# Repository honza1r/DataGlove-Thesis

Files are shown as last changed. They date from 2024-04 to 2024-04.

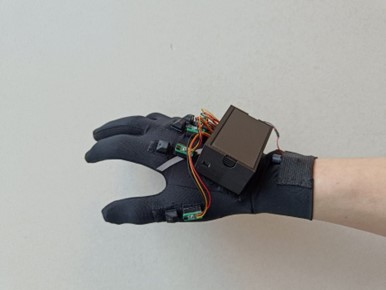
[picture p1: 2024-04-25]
Glove Pictures and Videos/Picture1.jpg

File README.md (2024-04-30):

# Open Source Dataglove - Master Thesis
This repository pools all of the technical files and instructions needed to replicate the dataglove that was developed as a master thesis. The repository is split into two main sections; hardware and software. 
## Hardware
The hardware section contains all production files as well as the microcontroller code. It also contains a matlab file with some matlab code and simulink model that was used very early in the development to test and create the Madgwick fusion algorithm. 
## Software
Software contains all intructions regarding connecting the glove to a ROS network running on a computer, as well as a unity application that serves as a demo for the glove. Connection to the demo is done over bluetooth serial.

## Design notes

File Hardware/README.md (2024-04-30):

# Hardware
All of the files given are the latest files and no previous versions are provided. That is mainly because the previous versions do not provide any value anymore.  
## PCB
It is important to note that the PCB contains a chip for regulating battery voltage to 5V,h however this chip seems to only work for about ~60 minutes and then causes a short circuit, killing itself and yhe battery. 
It is recommended to either use external power bank via the USB-C connector or you can redesign the PCB to have proper battery management.  
## ESP32 Code
The current code contains numerous functions that can be commented or uncommetned, depending on the desired data output. It is recommended to have a quick look over the main loop() function and its comments.
## CAD
The CAD files are given as STL and Siemens NX. A lot of the components are attached to the glove using velcro and velcro straps.
## MatLab
The simulink model used for developing and testing the Madgwick fusion algorithm is included. Also the Matlab script used for obtaining the magnetometer matrices is included.

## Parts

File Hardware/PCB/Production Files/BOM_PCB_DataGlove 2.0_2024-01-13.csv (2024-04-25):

ID | Name | Designator | Footprint | Quantity | Manufacturer Part | Manufacturer | Supplier | Supplier Part | Price
1 | SS54_C22452 | D2,D1 | SMA_L4.4-W2.8-LS5.4-R-RD | 2 | SS54 | MDD | LCSC | C22452 | 0.038
2 | SK12D07VG3_C431547 | SW1 | SW-TH_SK12D07VG3 | 1 | SK12D07VG3 | SHOU HAN | LCSC | C431547 | 0.017
3 | HDR-M-2.54_1x1 | J1,J2,J3,J4,J5 | HDR-M-2.54_1X1 | 5 |  |  | LCSC | C81276 | 0.007
4 | 100nF | ESPC17,ESPC18,ESPC20,ESPC21,ESPC22,ESPC23,ESPC7,ESPC3,ESPC5,ESPC8,ESPC9,ESPC11,ESPC12,ESPC16,C7 | C0402 | 15 | CL05B104KO5NNNC | SAMSUNG(三星) | LCSC | C1525 | 0.001
5 | 1uF | C1 | C0402 | 1 | CL05A105KA5NQNC | SAMSUNG(三星) | LCSC | C52923 | 0.004
6 | 100uF | C11 | C1206 | 1 | CL31A107MQHNNNE | SAMSUNG(三星) | LCSC | C15008 | 0.063
7 | 2.2uF | C12 | C0402 | 1 | CL05A225MQ5NSNC | SAMSUNG(三星) | LCSC | C12530 | 0.003
8 | XH-2AW_C2908611 | CN1 | CONN-TH_XH-2AW_C2908611 | 1 | XH-2AW | HCTL(华灿天禄) | LCSC | C2908611 | 0.011
9 | 10uF | ESPC19,ESPC1,ESPC2,ESPC10,ESPC13,ESPC14,ESPC15 | C0402 | 7 | CL05A106MQ5NUNC | SAMSUNG(三星) | LCSC | C15525 | 0.005
10 | 51kΩ | R18 | R0402 | 1 | 0402WGF5102TCE | UNI-ROYAL(厚声) | LCSC | C25794 | 0.001
11 | 750kΩ | R19 | R0603 | 1 | 0603WAF7503T5E | UNI-ROYAL(厚声) | LCSC | C23240 | 0.001
12 | 1MΩ | R21 | R0402 | 1 | 0402WGF1004TCE | UNI-ROYAL(厚声) | LCSC | C26083 | 0.001
13 | 200kΩ | R22 | R0402 | 1 | 0402WGF2003TCE | UNI-ROYAL(厚声) | LCSC | C25764 | 0.001
14 | DRV2605LDGSR | U5 | VSSOP-10_L3.0-W3.0-P0.50-LS4.9-BL | 1 | DRV2605LDGSR | TI(德州仪器) | LCSC | C527464 | 1.726
15 | 1-1825027-7 | U6,U7 | SW-TH_KH-6X6X4.3H-ZJ | 2 | 1-1825027-7 | TE Connectivity(美国泰科) | LCSC | C592923 | 0.169
16 | SM03B-SRSS-TB(LF)(SN)(P) | U10,U11,U12,U13,U14 | CONN-SMD_SM03B-SRSS-TB-LF-SN-P | 5 | SM03B-SRSS-TB(LF)(SN) | JST | LCSC | C160403 | 0.137
17 | AMS1117-3.3 | U4 | SOT-223-3_L6.5-W3.4-P2.30-LS7.0-BR | 1 | AMS1117-3.3 | AMS | LCSC | C6186 | 0.141
18 | LSM6DSO32TR | U3 | LGA-14_L3.0-W2.5-P0.50-TL | 1 | LSM6DSO32TR | ST(意法半导体) | LCSC | C1864162 | 7.011
19 | YTC1P-6030-01 | U1,U2 | CONN-SMD_YTC1P-3015-01 | 2 | YTC1P-6030-01 | YIYUAN(怡远) | LCSC | C5221285 | 0.111
20 | 4.7uF | ESPC6 | C0402 | 1 | CL05A475MP5NRNC | SAMSUNG(三星) | LCSC | C23733 | 0.006
21 | 22uF | ESPC4 | C0603 | 1 | CL10A226MQ8NRNC | SAMSUNG(三星) | LCSC | C59461 | 0.008
22 | 0805G (Green) | ESPLED2 | LED0805-R-RD | 1 | KT-0805翠绿 | KENTO | LCSC | C2297 | 0.014
23 | SS8050_C2150 | ESPQ1,ESPQ2 | SOT-23-3_L2.9-W1.3-P1.90-LS2.4-BR | 2 | SS8050 | CJ(江苏长电/长晶) | LCSC | C2150 | 0.015
24 | 5.1kΩ | ESPR1,ESPR2,ESPR3 | R0402 | 3 | 0402WGF5101TCE | UNI-ROYAL(厚声) | LCSC | C25905 | 0.001
25 | 22Ω | ESPR5 | R0402 | 1 | 0402WGF220JTCE | UNI-ROYAL(厚声) | LCSC | C25092 | 0.001
26 | 0Ω | ESPR6,ESPR7 | R0402 | 2 | 0402WGF0000TCE | UNI-ROYAL(厚声) | LCSC | C17168 | 0.001
27 | 10kΩ | ESPR8,ESPR9,ESPR16,ESPR17,ESPR18,ESPR19,ESPR20,R15,R13 | R0402 | 9 | 0402WGF1002TCE | UNI-ROYAL(厚声) | LCSC | C25744 | 0.001
28 | 22kΩ | ESPR10 | R0402 | 1 | 0402WGF2202TCE | UNI-ROYAL(厚声) | LCSC | C25768 | 0.001
29 | 47kΩ | ESPR11 | R0402 | 1 | 0402WGF4702TCE | UNI-ROYAL(厚声) | LCSC | C25792 | 0.001
30 | 1kΩ | ESPR12,R8,R14 | R0402 | 3 | 0402WGF1001TCE | UNI-ROYAL(厚声) | LCSC | C11702 | 0.001
31 | 470kΩ | R2 | R0402 | 1 | 0402WGF4703TCE | UNI-ROYAL(厚声) | LCSC | C25790 | 0.001
32 | SMF6.0CA_C2990473 | ESPU1,ESPU3,ESPU4 | SOD-123FL_L2.8-W1.8-LS3.7-BI | 3 | SMF6.0CA | Liown(里阳半导体) | LCSC | C2990473 | 0.029
33 | 6.8uH | L1 | IND-SMD_L4.5-W4.5_SMMS0420 | 1 | SMMS0420-6R8M | SXN(顺翔诺) | LCSC | C133194 | 0.194
34 | KT-0603R | LED1 | LED0603-RD | 1 | KT-0603R | KENTO | LCSC | C2286 | 0.006
35 | MMUN2133LT1G | Q1 | SOT-23-3_L2.9-W1.6-P1.90-LS2.8-BR | 1 | MMUN2133LT1G | onsemi(安森美) | LCSC | C86182 | 0.024
36 | 2MΩ | R4 | R0603 | 1 | 0603WAF2004T5E | UNI-ROYAL(厚声) | LCSC | C22976 | 0.001
37 | 680kΩ | R5 | R0603 | 1 | 0603WAF6803T5E | UNI-ROYAL(厚声) | LCSC | C25822 | 0.001
38 | 2N7002 | Q3,Q4 | SOT-23-3_L2.9-W1.3-P1.90-LS2.4-BR | 2 | 2N7002 | CJ(江苏长电/长晶) | LCSC | C8545 | 0.015
39 | HDR-F-2.54_1x2 | H8 | HDR-F-2.54_1X2 | 1 |  |  | LCSC | C49661 | 0.035
40 | AT24C256C-SSHL-T | AT24C256C | SOIC-8_L4.9-W3.9-P1.27-LS6.0-BL | 1 | AT24C256C-SSHL-T | MICROCHIP(美国微芯) | LCSC | C6482 | 0.396
41 | CP2102-GMR | CP2102 | WQFN-28_L5.0-W5.0-P0.50-BL-EP3.2 | 1 | CP2102-GMR | SILICON LABS(芯科) | LCSC | C6568 | 2.021
42 | ESP32-WROOM-32E(8MB) | ESP32 | WIFI-SMD_ESP32-WROOM-32E | 1 | ESP32-WROOM-32E-N8 | ESPRESSIF(乐鑫) | LCSC | C701342 | 3.661
43 | MMC5603NJ | MMC5603 | FLIPCHIP-4_L0.8-W0.8-R2-C2-P0.40-TL | 1 | MMC5603NJ | MEMSIC(美新) | Mouser | C404328 | 0.352
44 | TPS61090RSAR | TPS61090 | QFN-16_L4.0-W4.0-P0.65-BL-EP2.2 | 1 | TPS61090RSAR | TI(德州仪器) | LCSC | C206167 | 3.034
45 | TYPEC-304-ACP16 | USB-C | USB-C-SMD_TYPE-C-16P-1 | 1 | TYPEC-304-ACP16 | XUNPU(讯普) | LCSC | C2982555 | 0.127

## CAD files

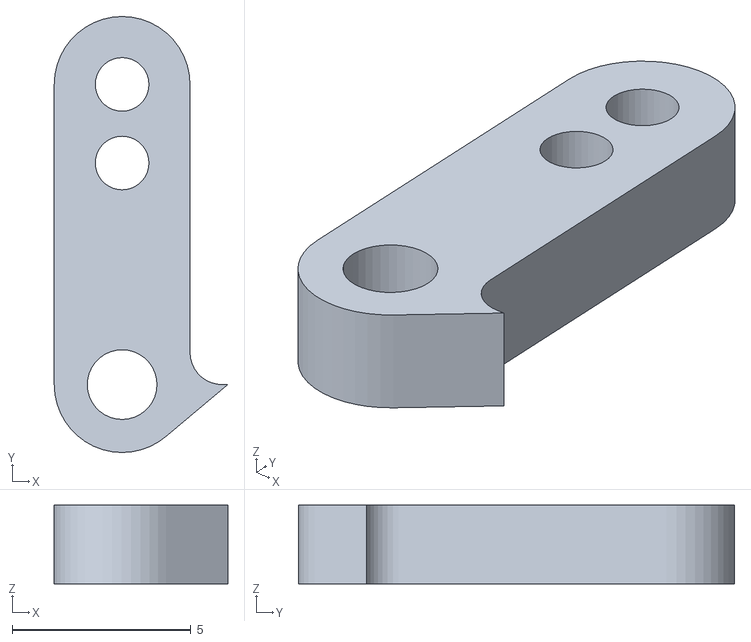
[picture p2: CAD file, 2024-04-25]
Hardware/CAD/Lever V3.stl
4.86 x 12.2 x 2.20

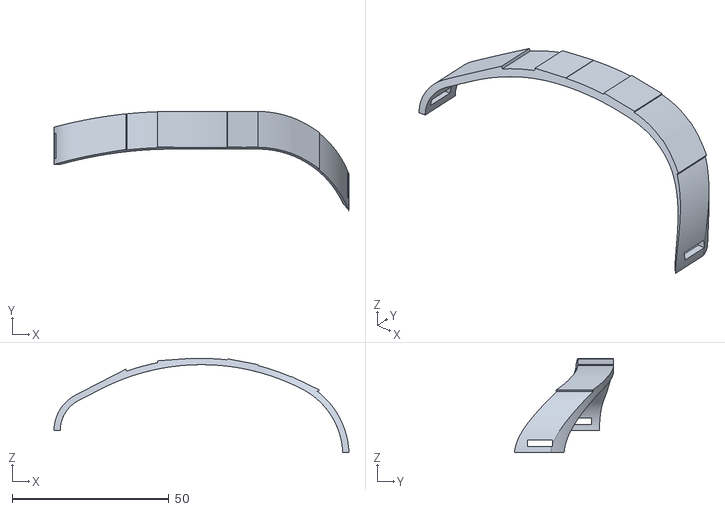
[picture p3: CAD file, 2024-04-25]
Hardware/CAD/Hand Strap V6.stl
94.0 x 31.6 x 30.0

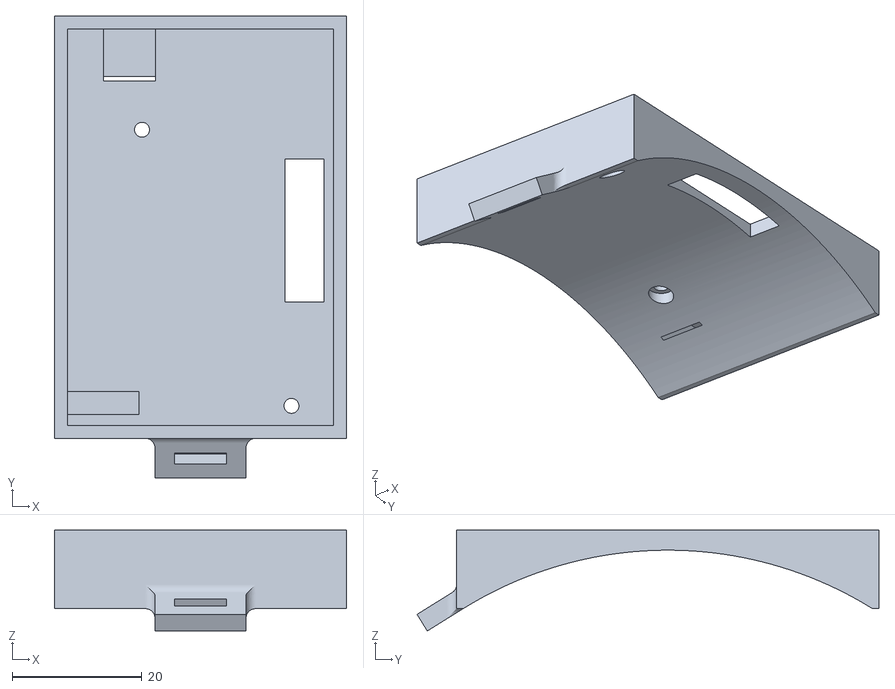
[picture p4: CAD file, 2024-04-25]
Hardware/CAD/Lower Part V2.stl
45.0 x 71.1 x 15.5

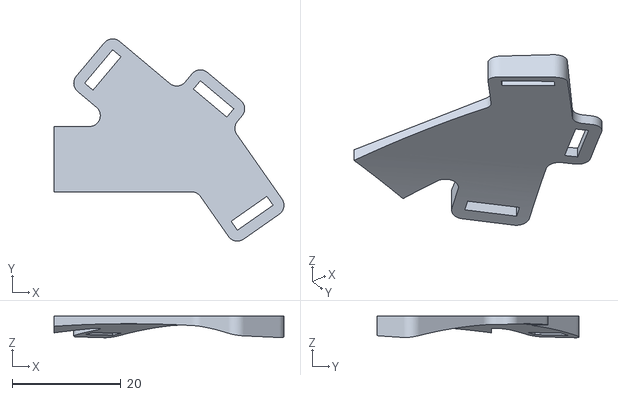
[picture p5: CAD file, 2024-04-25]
Hardware/CAD/Thumb Strap V2.stl
42.2 x 37.1 x 3.96

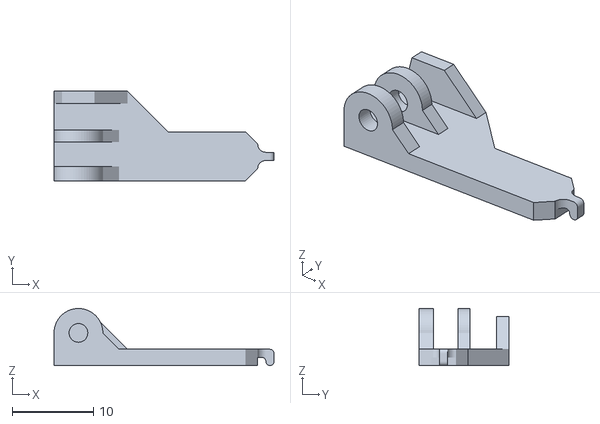
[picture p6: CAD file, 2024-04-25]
Hardware/CAD/Base V3.stl
27.0 x 11.0 x 7.00

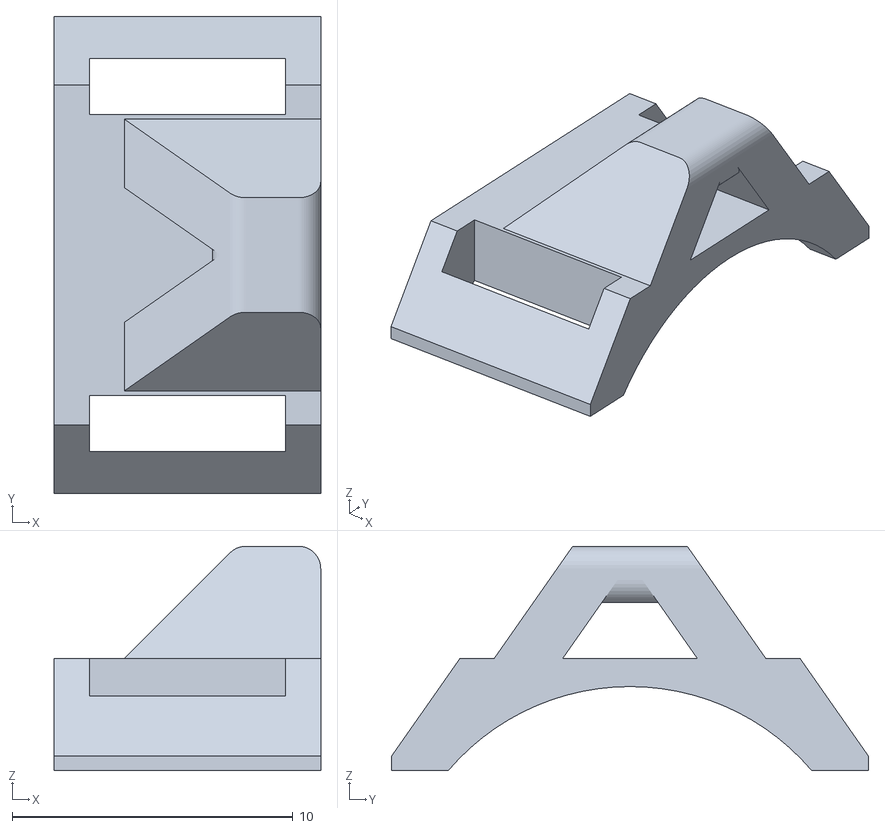
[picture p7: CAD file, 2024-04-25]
Hardware/CAD/String Holder V2.stl
9.50 x 17.0 x 8.00

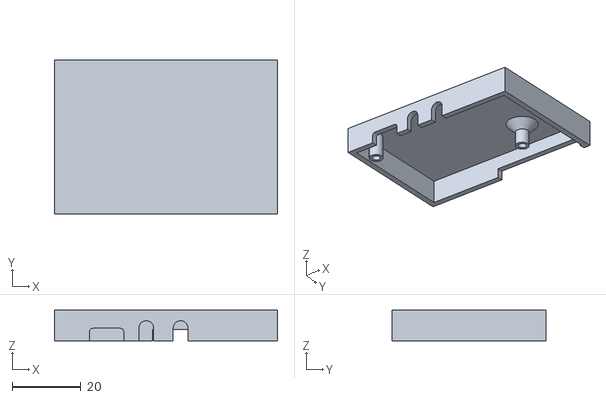
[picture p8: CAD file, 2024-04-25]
Hardware/CAD/Upper Part V2.stl
65.0 x 45.0 x 9.00

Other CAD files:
Hardware/CAD/Base V3.prt
Hardware/CAD/Hand Strap V6.prt
Hardware/CAD/Lever V3.prt
Hardware/CAD/Lower Part V2.prt
Hardware/CAD/String Holder V2.prt
Hardware/CAD/Thumb Strap V2.prt
Hardware/CAD/Upper Part V2.prt

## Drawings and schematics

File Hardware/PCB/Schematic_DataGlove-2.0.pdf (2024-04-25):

## USB-C Connection

## Power

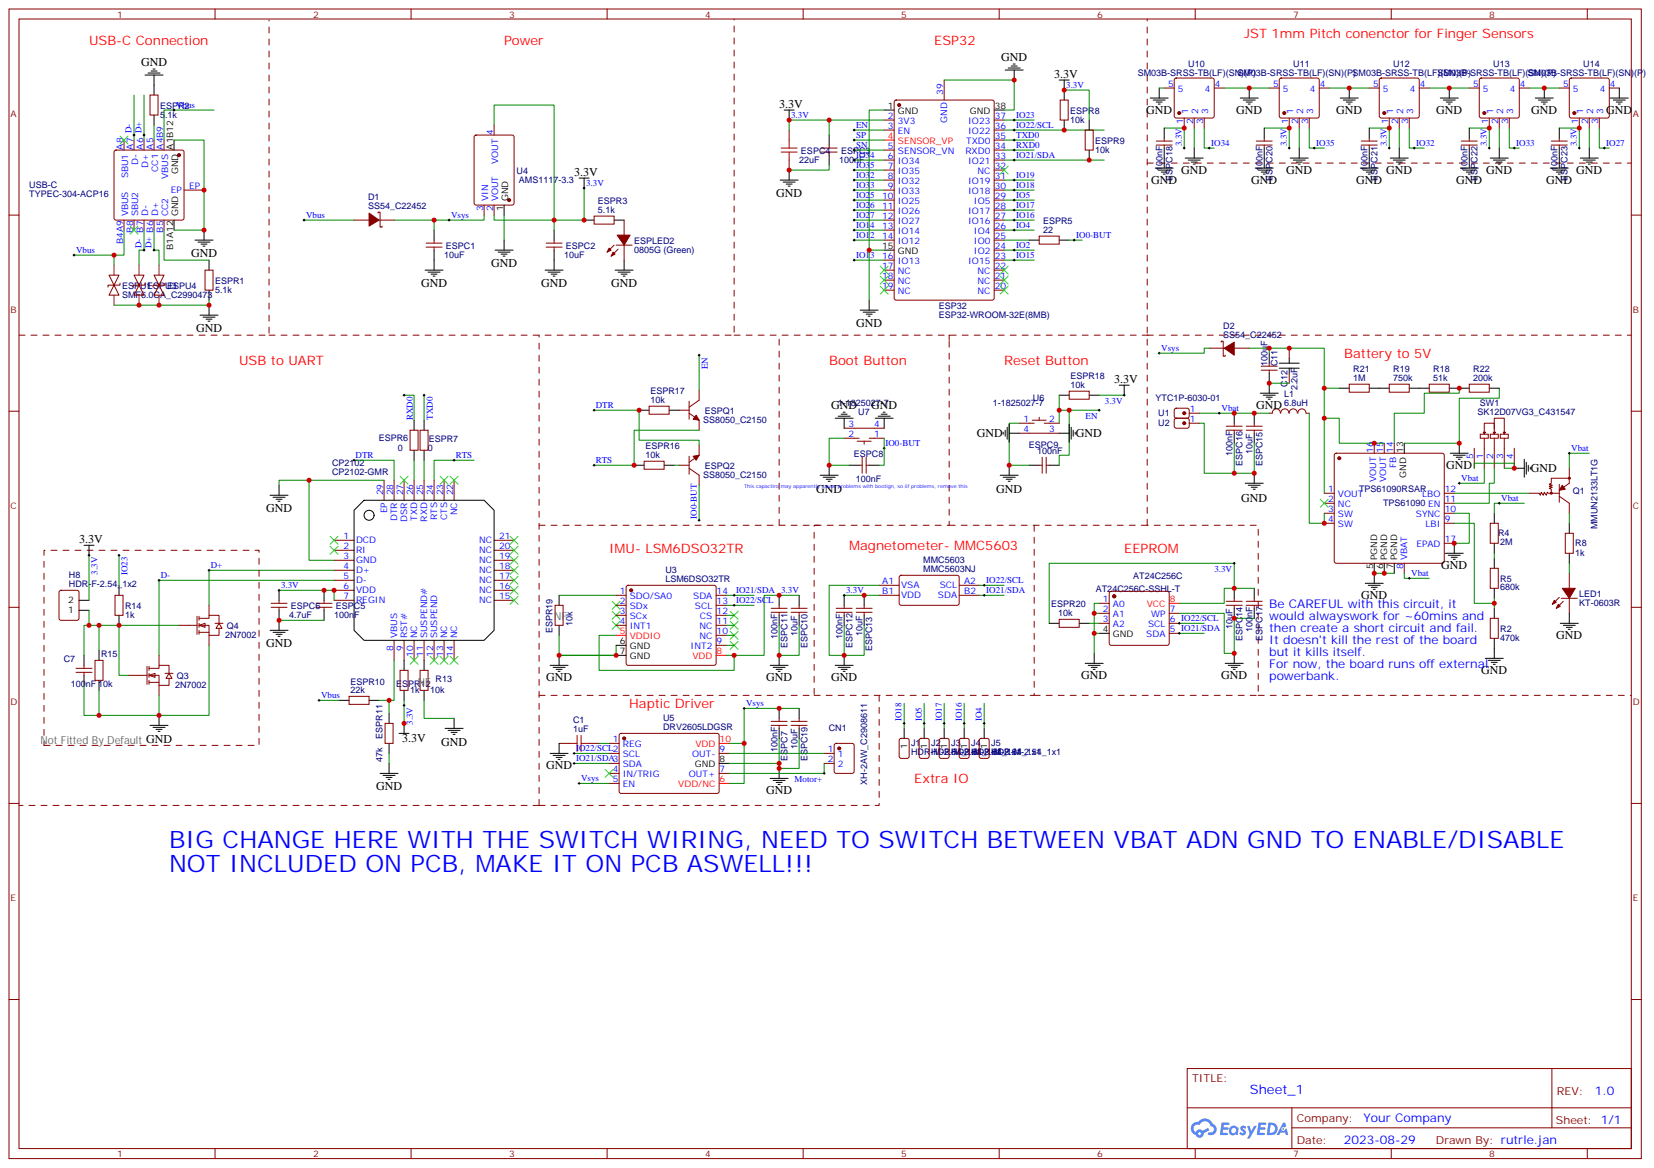
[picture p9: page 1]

JST 1mm Pitch conenctor for Finger Sensors

SM03B-SRSS-TB(LF)(SN)(P)

GND A1B12 VBUS A4B9 CC1 A5 D+ A6 D- A7 SBU1 A8 VBUS B4A9 SBU2 B8 D- B7 D+ B6 CC2 B5 GND B1A12

NC 22 CTS 23 RTS 24 RXD 25 TXD 26 DSR 27 DTR 28 EP 29 47k ESPR11

This capactiro may apparently cause problems with bootign, so iif problems, remove this

Be CAREFUL with this circuit, it
would alwayswork for ~60mins and
then create a short circuit and fail.
It doesn't kill the rest of the board
but it kills itself.
For now, the board runs off external
powerbank.

Not Fitted By Default

BIG CHANGE HERE WITH THE SWITCH WIRING, NEED TO SWITCH BETWEEN VBAT ADN GND TO ENABLE/DISABLE
NOT INCLUDED ON PCB, MAKE IT ON PCB ASWELL!!!

Drawn By: rutrle.jan

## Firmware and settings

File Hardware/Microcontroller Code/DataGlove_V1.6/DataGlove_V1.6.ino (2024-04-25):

#include <Wire.h>
#include <BasicLinearAlgebra.h>
#include "BluetoothSerial.h"
#include "Adafruit_DRV2605.h"

Adafruit_DRV2605 drv;//define the on-board hpatic feedback motor drive ic

const char *pin = "1234"; // Change this to more secure PIN.
String device_name = "ESP32-DataGlove";

#if !defined(CONFIG_BT_ENABLED) || !defined(CONFIG_BLUEDROID_ENABLED)
#error Bluetooth is not enabled! Please run `make menuconfig` to and enable it
#endif

#if !defined(CONFIG_BT_SPP_ENABLED)
#error Serial Bluetooth not available or not enabled. It is only available for the ESP32 chip.
#endif

BluetoothSerial SerialBT;

using namespace BLA;

int IMUAdress = 0x6A;
int magnetometerAdress = 0x30;
int EEPROMAdress = 0x54;

//finger pings
#define thumb 34
#define index 35
#define middle 32
#define ring 33
#define pinky 27

//finger variables
int thumb_angle = 0;
int index_angle = 0;
int middle_angle = 0;
int ring_angle = 0;
int pinky_angle = 0;

//vibration variables
bool effectActivated = false;

//sensor variables
float magnetometer_cal [3]= {0.0,0.0,0.0};
float accel_cal [3] = {0.0,0.0,0.0};//I call it cal but techniccally it is the raw data, as we do not calibrate it, however it will be easier to understand the madgwick filter if all variables used there are called cal (preventing confusion)
float g [3] = {0.0,0.0,0.0};

//magnetometer corection matrices variables, to be read from EEPROM
typedef union{
  float number;
  uint8_t bytes[4];
} FLOATUNION_t; //this should allow me to access the individual float both as a float and as four bytes (the bytes I can the write and read from EEPROM one by one)
//for now, magnetometer correction matrices are defined here, they can be saved to the EEPROM if desired
float A_noMagnet[3][3] = {{0.972278205290896,0.025006895510657,-0.002802863108999},{0.025006895510657,0.982439238433754,0.021710960624373},{-0.002802863108999,0.021710960624373,1.048073705414568}};
float b_noMagnet[3] = {11.793363227227841,-45.088424713421226,-3.201333342740616};

// float A_to_save[9] = {1.0,0.0,0.0,0.0,1.0,0.0,0.0,0.0,1.0};//change these arrays with the values that you want saved
// float b_to_save[3] = {-96.207731134594850,-21.082673512359378,-42.121805843179710};

//output varaibles
float roll = 0.0;
float pitch = 0.0;
float yaw = 0.0;
float qx = 0.0;
float qy = 0.0;
float qz = 0.0;
float qw = 0.0;

//EKF Variables
float q[4] = {1.0,0.0,0.0,0.0}; //initial orientation, doesnt matter cause the filter converts to actaul orientation right away
float P[4][4] = {{0.1,0.0,0.0,0.0},
                 {0.0,0.1,0.0,0.0},
                 {0.0,0.0,0.1,0.0},
                 {0.0,0.0,0.0,0.1}};//currently defined as a full matrix, but once we do efficiecny optimalization, we'll probably find that we dont need to define the full matrix
float R_mag = 2.0;//the actaul estiamtions of R for accelerometer and magnetometer, shouldnt need to be tuned
float R_acc = 0.001;
float Q_val = 0.05;
//all of the following values are tunable and determine how well the filter will perform
float R_mag_max = 10.0;//2
float R_acc_max = 0.5;//1.0
float Q_max = 5.0;//0.1
float R_mag_min = 0.001;//1.0
float R_acc_min = 0.001;
float Q_min = 0.01;//0.01
float R_mag_slope = 10;//1
float R_acc_slope = 0.0005;//0.005
float Q_slope = 7.5;//0.1

//Madgwick Variables
float q0 = 1.0;
float q1 = 0.0;
float q2 = 0.0;
float q3 = 0.0;
float qDot1 = 0.0;
float qDot2 = 0.0;
float qDot3 = 0.0;
float qDot4 = 0.0;

float sampleFrequency = 200.0; //update frequency in Hz
int dataCounterLimit = int(sampleFrequency/25);//ensure we always send data to unity at 25hz
int dataCounter = 0;
int delayTime = int(1000/sampleFrequency);//1000 to make sure it is in MILLISECONDS!!!

bool inPairingMode = false;
unsigned long lastPairingCheckTime = 0;
const unsigned long pairingCheckInterval = 10000; // Check every 10 seconds

uint16_t dataOn = 25;
uint16_t dataOn_counter = 0;
uint16_t dataOff = 25;
uint16_t dataOff_counter = 0;


void setup() {
  Serial.begin(115200);
  SerialBT.begin(device_name);
  Serial.printf("The device with name \"%s\" is started.\nNow you can pair it with Bluetooth!\n", device_name.c_str());
  Wire.begin();
  magnetometerSetup();
  IMUSetup();
  // drv.begin();
  // drv.selectLibrary(1);
  // drv.setMode(DRV2605_MODE_INTTRIG); 
  // saveMagnetometerMatrices(A_to_save, b_to_save);//matrix A is ROW MAJOR, essentially spread into a noodle
  // delay(1000);
  // readMagnetometerMatrices();
  delay(1000);
}

void loop() {
  //magToCSV();//only uncomment in need of calibration of the magnetometer,sends magnetometer data in csv format, that can the be imported to Matlab
  readFingers();
  collectMagnetometerData();
  collectIMUData();
  //uncomment whichever filter you want to use
  EKF();
  //MadgwickFilter();
  //vibrations();//control the vibration feedback motor
  dataCounter++;
  if (dataCounter >= dataCounterLimit){
    printAnglesBT();//sends values over BT
    //sendCSVBT();//sends values over BT in CSV format
    //printAngles();//sends values over serial
    //Following block of code was used for smapling gestures, it send data for 1s and stops sending for 1s
//     if(dataOn_counter < dataOn){
//      sendCSVBT();
//      dataOn_counter++;
//     } 
//     else if(dataOff_counter < dataOff){
//       dataOff_counter++;
//     }
//     else{
//       dataOn_counter = 0;
//       dataOff_counter = 0;
//     }
    dataCounter = 0;
  }
  delay(delayTime);
}

void magnetometerSetup(){
  writeRegister(magnetometerAdress, 0x1C, 2);//configure Internal Control 1
  writeRegister(magnetometerAdress, 0x1A, 208);//configure ODR
  writeRegister(magnetometerAdress, 0x1B, 160);//configure Internal Control 0
  writeRegister(magnetometerAdress, 0x1D, 16);//configure Internal Control 2
}

void IMUSetup(){//watch out when using the slightly different chips (ranges and according mechanical characteristics!!!), relates to then transalting the output to proper units
  //this code has settigns for LSM6DSO
  writeRegister(IMUAdress, 0x10, 82);//configure CTRL1_XL, +-2g range, low-pass filter enable
  writeRegister(IMUAdress, 0x11, 84);//configure CTRL2_G, +-500DPS
  writeRegister(IMUAdress, 0x12, 4);//configure CTRL3_C
  writeRegister(IMUAdress, 0x13, 2);//configure CTRL4_C
  writeRegister(IMUAdress, 0x15, 7);//configure CTRL6_C, gyro filter bandwidth 12.2Hz (lowest) = 7
  writeRegister(IMUAdress, 0x17, 160);//configure CTRL8_XL, accell low-pas filter at 10Hz (ish), very low, 10.4Hz = 64, 2.08hz = 128, 1.04Hz = 160
  writeRegister(IMUAdress, 0x18, 226);//configure CTRL9_XL
}

void vibrations(){
  if (thumb_closed && index_closed && middle_closed && ring_closed && pinky_closed){
    if(!effectActivated){
      drv.setWaveform(0, 1);
      drv.setWaveform(1,0);
      drv.go();
      effectActivated = true;
    }
  }
  else{
    effectActivated = false;
  }
}

void collectMagnetometerData(){
  float magnetometer_raw [3] = {0.0,0.0,0.0};
  uint8_t buffer [9] = {0,0,0,0,0,0,0,0,0};
  int32_t x = 0;
  int32_t y = 0;
  int32_t z = 0;

  Wire.beginTransmission(magnetometerAdress);//start communication with magnetometer
  Wire.write(0x00);//access first output register (Xout0)
  Wire.endTransmission();//end communication with slave
  Wire.requestFrom(magnetometerAdress,9);//request all output bytes (until and including OUTZ_H_A)
  while(Wire.available() < 9);//wait until all bytes are received
  for (int i = 0; i < 9; i++){//feed all data into the buffer array
    buffer[i] = Wire.read();
  }

  x = (uint32_t)buffer[0] << 12 | (uint32_t)buffer[1] << 4 | (uint32_t)buffer[6] >> 4;//piece together all the bytes corresponding to 1 axis
  y = (uint32_t)buffer[2] << 12 | (uint32_t)buffer[3] << 4 | (uint32_t)buffer[7] >> 4;
  z = (uint32_t)buffer[4] << 12 | (uint32_t)buffer[5] << 4 | (uint32_t)buffer[8] >> 4;

  x -= (uint32_t)1 << 19;//fix center offsets(something to do with the fact data is sent unsigned but we need to make it singed, I think)
  y -= (uint32_t)1 << 19;
  z -= (uint32_t)1 << 19;

  magnetometer_raw[0] = float(x)*0.00625;//convert from count directly to uT (based on datasheet)
  magnetometer_raw[1] = float(y)*0.00625;
  magnetometer_raw[2] = float(z)*0.00625;
  //correct for soft and hard irons

  float magnetometer_corr [3] = {magnetometer_raw[0]-b_noMagnet[0], magnetometer_raw[1]-b_noMagnet[1], magnetometer_raw[2]-b_noMagnet[2]};
    magnetometer_cal[0] = {magnetometer_corr[0]*A_noMagnet[0][0]+magnetometer_corr[1]*A_noMagnet[1][0]+magnetometer_corr[2]*A_noMagnet[2][0]};
    magnetometer_cal[1] = {magnetometer_corr[0]*A_noMagnet[0][1]+magnetometer_corr[1]*A_noMagnet[1][1]+magnetometer_corr[2]*A_noMagnet[2][1]};
    magnetometer_cal[2] = {magnetometer_corr[0]*A_noMagnet[0][2]+magnetometer_corr[1]*A_noMagnet[1][2]+magnetometer_corr[2]*A_noMagnet[2][2]};
}

void collectIMUData(){
  float gyro_raw [3] = {0.0,0.0,0.0};
  float gyro_corr [3] = {0.01,-0.01,0.01};//this is a bias which is measured as the average vlaue of 100+ samples with the sensor at rest

  float accel_raw [3] = {0.0,0.0,0.0};
  
  Wire.beginTransmission(IMUAdress);//start communication with IMU
  Wire.write(0x22);//access first output register (OUTX_L_G)
  Wire.endTransmission();//end communication with slave
  Wire.requestFrom(IMUAdress,12);//request all output bytes (until and including OUTZ_H_A)
  while(Wire.available() < 12);//wait until all bytes are received

  //the output data is in some weird unit, so we multiply by 35 as based on table 3(mechanical characteristics) and the chosen range, and then by 3.14/(180.0*1000.0) to get it from mdps to rad/s
  //35.0*3.14/(180.0*1000.0)=0.000610865
  gyro_raw[0] = float(int16_t(Wire.read()|(Wire.read()<<8)));//read first byte (low byte of GYRO_X) and combine it with the second byte (high byte of GYRO_X) that has been shifted to the left), so on for the other variables
  gyro_raw[1] = float(int16_t(Wire.read()|(Wire.read()<<8)));//gotta make sure the two bytes read are interpreted correctly as a signed 16 bit integer and then we convert to float
  gyro_raw[2] = float(int16_t(Wire.read()|(Wire.read()<<8)));

  //the output data is in some weird unit, so we multiply by 0.244 as based on table 3(mechanical characteristics) and the chosen range, and then by 9.81/1000 to trasnfer from mg to m/s^2
  //0.244*9.81/1000.0=0.00239364, I cahnged range so it goes from 0.244 to 0.061
  accel_cal[0] = float(int16_t(Wire.read()|(Wire.read()<<8)))*0.00059841;
  accel_cal[1] = float(int16_t(Wire.read()|(Wire.read()<<8)))*0.00059841;
  accel_cal[2] = float(int16_t(Wire.read()|(Wire.read()<<8)))*0.00059841;  

  //the output data is in some weird unit, so we multiply by 35 as based on table 3(mechanical characteristics) and the chosen range, and then by 3.14/(180.0*1000.0) to get it from mdps to rad/s
  //35.0*3.14/(180.0*1000.0)=0.000610865, went form 1000DPS to 500DPS (so constant = 0.0003054325)
  g[0] = gyro_raw[0]*0.0003054325-gyro_corr[0];
  g[1] = gyro_raw[1]*0.0003054325-gyro_corr[1];
  g[2] = gyro_raw[2]*0.0003054325-gyro_corr[2];
}

void MadgwickFilter(){
  float beta = 2.0; //this is the main value we want to tune for the filter, it acts the same way as Kp in a PID controller,1, actaullly it is the elarning rate in gradient descent
  float qDot1 = 0.5*(-q1*(g[0]) - q2*(g[1]) - q3*(g[2]));
  float qDot2 = 0.5*(q0*(g[0]) + q2*(g[2]) - q3*(g[1]));
  float qDot3 = 0.5*(q0*(g[1]) - q1*(g[2]) + q3*(g[0]));
  float qDot4 = 0.5*(q0*(g[2]) + q1*(g[1]) - q2*(g[0]));

  float recipNorm = 0.0;

  if (!((accel_cal[0] == 0.0) && (accel_cal[1] == 0.0) && (accel_cal[2] == 0.0))){//ensures we only compute update if accelerometer readings are valid
    //normalize accelerometer readings
    recipNorm = 1/(sqrt(accel_cal[0]*accel_cal[0]+accel_cal[1]*accel_cal[1]+accel_cal[2]*accel_cal[2]));
    float ax = accel_cal[0]*recipNorm;
    float ay = accel_cal[1]*recipNorm;
    float az = accel_cal[2]*recipNorm;
    //normalize magnetometer readings
    recipNorm = 1/(sqrt(magnetometer_cal[0]*magnetometer_cal[0]+magnetometer_cal[1]*magnetometer_cal[1]+magnetometer_cal[2]*magnetometer_cal[2]));
    float mx = magnetometer_cal[0]*recipNorm;
    float my = magnetometer_cal[1]*recipNorm;
    float mz = magnetometer_cal[2]*recipNorm;
    //the following varaibles are "pre-calculated" once so we save some computatonal time by not doing the calcualtions over and over again when they are needed
    float twoq0mx = 2.0*q0*mx;
    float twoq0my = 2.0*q0*my;
    float twoq0mz = 2.0*q0*mz;

    float twoq1mx = 2.0*q1*mx;

    float twoq0 = 2.0*q0;
    float twoq1 = 2.0*q1;
    float twoq2 = 2.0*q2;
    float twoq3 = 2.0*q3;

    float twoq0q2 = 2.0*q0*q2;
    float twoq2q3 = 2.0*q2*q3;

    float q0q0 = q0*q0;
    float q0q1 = q0*q1;
    float q0q2 = q0*q2;
    float q0q3 = q0*q3;
    float q1q1 = q1*q1;
    float q1q2 = q1*q2;
    float q1q3 = q1*q3;
    float q2q2 = q2*q2;
    float q2q3 = q2*q3;
    float q3q3 = q3*q3;
    //reference direction of Earth's magnetic field
    float hx = mx*q0q0 - twoq0my*q3 + twoq0mz*q2 + mx*q1q1 + twoq1*my*q2 + twoq1*mz*q3 - mx*q2q2 - mx*q3q3;
    float hy = twoq0mx*q3 + my*q0q0 - twoq0mz*q1 + twoq1mx*q2 - my*q1q1 + my*q2q2 + twoq2*mz*q3 - my*q3q3;

    float twobx = sqrt(hx*hx + hy*hy);
    float twobz = -twoq0mx*q2 + twoq0my*q1 + mz*q0q0 + twoq1mx*q3 - mz*q1q1 + twoq2*my*q3 - mz*q2q2 + mz*q3q3;
    float fourbx = 2.0*twobx;
    float fourbz = 2.0*twobz;

    float s0 = -twoq2 * (2.0 * q1q3 - twoq0q2 - ax) + twoq1 * (2.0 * q0q1 + twoq2q3 - ay) - twobz * q2 * (twobx * (0.5 - q2q2 - q3q3) + twobz * (q1q3 - q0q2) - mx) + (-twobx * q3 + twobz * q1) * (twobx * (q1q2 - q0q3) + twobz * (q0q1 + q2q3) - my) + twobx * q2 * (twobx * (q0q2 + q1q3) + twobz * (0.5 - q1q1 - q2q2) - mz);
    float s1 = s1 = twoq3 * (2.0 * q1q3 - twoq0q2 - ax) + twoq0 * (2.0 * q0q1 + twoq2q3 - ay) - 4.0 * q1 * (1 - 2.0 * q1q1 - 2.0 * q2q2 - az) + twobz * q3 * (twobx * (0.5 - q2q2 - q3q3) + twobz * (q1q3 - q0q2) - mx) + (twobx * q2 + twobz * q0) * (twobx * (q1q2 - q0q3) + twobz * (q0q1 + q2q3) - my) + (twobx * q3 - fourbz * q1) * (twobx * (q0q2 + q1q3) + twobz * (0.5 - q1q1 - q2q2) - mz);
    float s2 = -twoq0 * (2.0 * q1q3 - twoq0q2 - ax) + twoq3 * (2.0 * q0q1 + twoq2q3 - ay) - 4.0 * q2 * (1 - 2.0 * q1q1 - 2.0 * q2q2 - az) + (-fourbx * q2 - twobz * q0) * (twobx * (0.5 - q2q2 - q3q3) + twobz * (q1q3 - q0q2) - mx) + (twobx * q1 + twobz * q3) * (twobx * (q1q2 - q0q3) + twobz * (q0q1 + q2q3) - my) + (twobx * q0 - fourbz * q2) * (twobx * (q0q2 + q1q3) + twobz * (0.5 - q1q1 - q2q2) - mz);
    float s3 = s3 = twoq1 * (2.0 * q1q3 - twoq0q2 - ax) + twoq2 * (2.0 * q0q1 + twoq2q3 - ay) + (-fourbx * q3 + twobz * q1) * (twobx * (0.5 - q2q2 - q3q3) + twobz * (q1q3 - q0q2) - mx) + (-twobx * q0 + twobz * q2) * (twobx * (q1q2 - q0q3) + twobz * (q0q1 + q2q3) - my) + twobx * q1 * (twobx * (q0q2 + q1q3) + twobz * (0.5 - q1q1 - q2q2) - mz);

    recipNorm = 1/sqrt(s0*s0 + s1*s1 + s2*s2 + s3*s3);
    s0 *= recipNorm;
    s1 *= recipNorm;
    s2 *= recipNorm;
    s3 *= recipNorm;

    qDot1 -= beta*s0;
    qDot2 -= beta*s1;
    qDot3 -= beta*s2;
    qDot4 -= beta*s3;
  }

  q0 += qDot1/sampleFrequency;
  q1 += qDot2/sampleFrequency;
  q2 += qDot3/sampleFrequency;
  q3 += qDot4/sampleFrequency;

  recipNorm = 1/sqrt(q0*q0 + q1*q1 + q2*q2 + q3*q3);
  q0 *= recipNorm;
  q1 *= recipNorm;
  q2 *= recipNorm;
  q3 *= recipNorm;

  roll = atan2f(q0*q1 + q2*q3, 0.5 - q1*q1 - q2*q2)*180.0/3.14;
  pitch = asinf(-2.0*(q1*q3 - q0*q2))*180.0/3.14;
  yaw = atan2f(q1*q2 + q0*q3, 0.5 - q2*q2 - q3*q3)*180.0/3.14;
  qw=q0;
  qx=q1;
  qy=q2;
  qz=q3;
}
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

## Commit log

2023-12-09 Arduino Codes for the Glove- all versions
2023-12-09 All PCB Files
    [BOM of manual components.xlsx, BOM_PCB_Battery Management_2023-09-04.csv, BOM_PCB_Battery Management_2023-12-09.csv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]
